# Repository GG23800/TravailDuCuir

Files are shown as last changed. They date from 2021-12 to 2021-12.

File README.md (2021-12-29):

# TravailDuCuir

Dans ce dossier presente certains projets de maroquinerie. On y trouvera les patrons utilisé quelques conseils éventuels pour la fabrication. Les patrons peuvent être utilisé pour des projets personnels mais pas pour faire des pièces qui seront vendues sans autorisation préalable de l'auteur.

## Pièce présentent dans ce dossier

### Sacoche de boules de pétanque



## Recettes

### Colle de farine

Pour coller le cuir j'utilise une simple colle de farine. Cette colle permet est colle "faible", elle permet de coller deux bouts de cuir entre eux mais la fixation n'est pas très solide. Elle est suffisante pour le maintient afin de coudre ensuite les pièces de cuir.

Pour la préparer :

- 2-3 cuillères à soupe de farine
- 1 cuillère à caffé de sucre en poudre (optionnel)
- un verre d'eau

Tout mélanger dans une casserole et faire chauffer. Quand la préparation commence à épaissir, rajouter de l'eau si nécessaire pour obtenir la consistance voulue. Elle doit être visqueuse mais pas trop pour pouvoir être étalée.

Conserver la colle au frigot, elle se garde quelques jours.

### Encaustique

L'encaustique est composé de :

- une part de cire d'abeille
- une part d'essence de térébentine

On peut également rajouter de l'huile de lin.

L'encaustique est déposé en finition, il nourrit le cuir et sert à imperméabiliser le cuir. Plus on en met plus l'imperméabilisaiton sera efficace. Par contre si on en met trop sur du cuir souple, il peut craqueler et faire apparaitre des tâche blanches. La première couche peut être mise avec une brosse à dent souple ainsi il peut se déposer dans le couture pour les protéger. Ensuite on le frotte avec un tissu doux non pelucheux.

## Freecad

Pour creer un pdf avec le patron à l'échelle 1, on utilise freecad (logiciel de CAO open source). On commence par créer une nouvelle pièce (module part design), on défini la géométrie avec le module sketch, on extrude (il est nécessaire de faire une pièce 3D pour exporter un dessin en coupe de la pièce). Une fois la pièce terminée, on ouvre le module drawing et le dessin s'intègrea avec la fonction insérer une projection orthogonale (on choisit la bonne vue pour l'affichage), on décoche la checkbox Echelle/position auto et on force l'échelle à 1. 
Sélectionner la page (du drawing) et appuyer sur la valeur de Editable texts, puis sur le bouton avec les trois petits points, on peut alors modifier les champs de la cartouche.
Finnalement on créé le fichier pdf via Fichier->Expoter au format pdf.

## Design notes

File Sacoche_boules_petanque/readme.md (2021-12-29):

# Sacoche de boules de pétanques

Ce dossier contient des patrons (fait à l'aide du logiciel freecad) pour découper les pièces permettant de monter une sacoche de boules de pétanques en cuir souple. Cette sacoche a été conçu pour des boules de 74 mm de diamètre.

## Matériel

- [Cuir de basane](https://www.decocuir.com/peau-cuir-basane-tannage-vegetal-france-065-c2x36476475)
- [Teinture acajou](https://www.decocuir.com/teinture-base-aqueuse-eco-flo-130ml-acajou-fonce-dark-mahogany-c2x35737638)
- [Fil de lin rouge](https://www.decocuir.com/fil-lin-cartonnette-15m-couture-mercerie-cuir-c2x36667080)
- [Fil de lin marron chocolat](https://www.decocuir.com/fil-lin-carde-cire-poisse-c2x36667077)
- [Boucle à rouleau](https://www.decocuir.com/boucle-a-rouleau-a-ardillon-laiton-vieilli-15-mm-c2x36300452) couleur laiton vieilli

## Pièces

Dans cette section on montre les patrons des différentes pièces composant la sacoche. Les fichiers des patrons peuvent être retrouvés dans le dossier [Patrons](./Patrons).

Attentions, les images insérées dans ce document ne sont pas à l'échelle, pour des patrons à l'échelle il faut utiliser les fichiers pdf du dossier Patrons.

Des lignes droites peuvent apparaître au milieu des patrons, ces lignes sont des lignes de symétrie qui reste affiché lors de la mise en plan.

### Anse



On a mis deux fichiers de patrons pour la anse car la dimension est supérieur à une feuille A4. Le fichier [Demi anse](./Patrons/Demi_anse.pdf) donne le patron de la moitié de la anse qui tient sur une page A4, il faudra l'imprimer deux fois et scotché bout à bout les deux parties. Sinon dans le fichier [Anse](./Patrons/Anse.pdf) on a mis la anse totale (elle dépasse légèrement du cadre) qu'il faudra imprimer sur une feuille A3.

La anse fait 400 mm de long pour 16 mm de large. Les pads sont des carrés de 30x30 mm.

### Support de boucle



Lien vers le [patron](./Patrons/Support_de_boucle.pdf) du support de boucle.

### Sangle



Lien vers le [patron](./Patrons/Sangle.pdf) de la sangle.

Pour plus de solidité (et avoir de la fleur de chaque côté de la anse) nous l'avons doublé. Dû à la souplesse du patron en papier et du cuir les deux pièces ne sont pas très bien superposées, il a donc fallu les égaliser après collage (avant couture).

### Côté

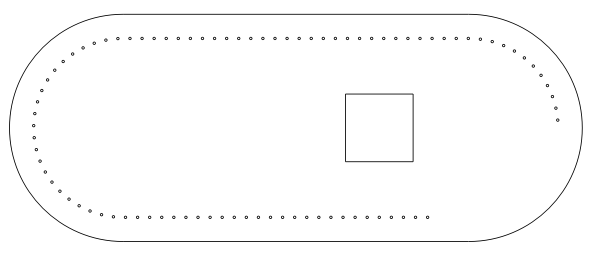
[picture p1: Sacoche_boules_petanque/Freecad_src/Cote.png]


Lien vers le [patron](./Patrons/Cote.pdf) du côté.

Attention pour les deux côtés de la sacoche sont simétriques, donc pour ce qui concerne la couture il faut utiliser le patron dans un sens pour le côté gauche et dans l'autre pour le côté droit.

On a mis une distance de 10 mm entre le bord de la pièce et la ligne de couture. Les points de couture sont espacés de 5 mm. Le carré représente le positionnement de la anse sur cette pièce, la dimension est légèrement inférieur (de 2 mm) au bout de la anse pour donner un indicateur de dépose de colle et ne pas avoir de marque qui peuvent dépasser de la anse une fois fixé. 

### Pourtour



Le pourtour est la plus grande pièce du projet. Elle fait environ 640 mm de long, soit deux longueurs de feuille A4 plus l'arrondi. Le patron est donc enregistré au [format A3](./Patrons/Pourtour_A3.pdf) en plusieurs parties. Il faudra les scotcher bout à bout. Le patron au [format 4A](./Patrons/Pourtour_A4.pdf) montre la pièce complète.

On a mis une distance de 10 mm entre le bord de la pièce et la ligne de couture. Les points de couture sont espacés de 5 mm.

## Montage

La anse étant faite dans le même cuir que tout le reste, on l'a doublé pour augmenter sa solidité. Il faut donc découper deux fois le patron de la anse, coller les deux parties ensemble puis les coudres avec un point sellier. Ne pas oublié le travail des tranches (abat carre, ponsage, gomme adragante).

Pour le support de boucle, il préférable de parer la partie à coller pour fixer la boucle. Une fois collée, on coud pour la solidité. Sur le patron, l'enchapure n'a pas les boûts arrondis, on peut le faire à l'emporte pièce. Il n'y a pas de patron à l'heure actuelle, mais il est également préférable de faire un passant. Ce passant doit être mis sur le patron avant la mise en place de la boucle.

Les côtés doivent être découpés en deux exemplaires. La anse est fixée sur chaque côté puis cousue. Une fois ceci effectué, on coud les côtés et le pourtour. Les côtés et le pourtoure doivent être cousu à l'envers (face teinte l'une contre l'autre), le perçage s'effectue avec une alène ronde. Le couture est doublée (type point sellier avec deux aiguilles). Cette couture a été faite avec le fil marron pour qu'elle soit discrète (toutes les autres coutures ont été faite au fil rouge).

Une fois la couture fini, on retourne la sacoche pour qu'elle soit à l'endroit.

Pour la permière sacoche, le support de boucle et la sangle ont été fixés et cousu après cette couture pour bien les positionner. Si les patrons était bien maitrisés on pourrai le faire avant.

### Remarques

Le pourtour est un peu grand et peut être réduit d'un ou deux centimètres.

La sangle est un peu grande et peut être réduit d'un centimètre.

Attention, le nombre de trou pour la couture des côté et du pourtour n'est pas maitrisé. Ces trous n'ont pas été marqués à l'alène sur la fleur mais au marqueur sur la croute. Les trous ont été percés au fur et à mesure puis quand la couture a été jugé suffisament haute (et pas trop) on s'est arrêté. Remonter un quart du demi-cercle supérieur des côtés est suffisant voir un peu trop.

## Photos 

Différentes photos du porjet sont enregistrées dans le dossier [Photos](./Photos).



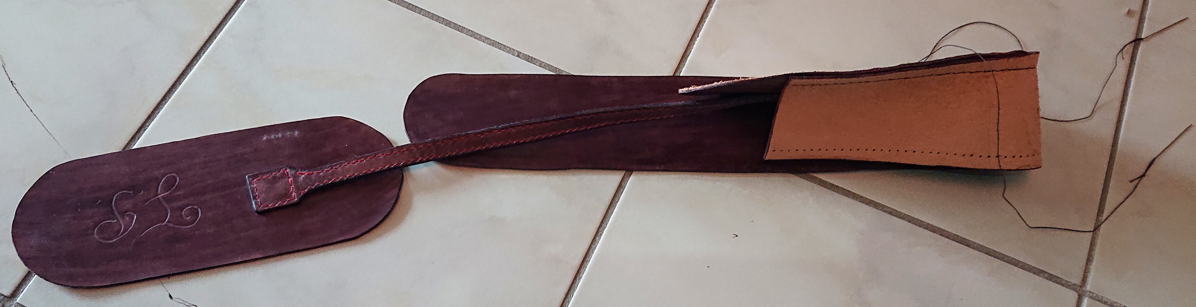
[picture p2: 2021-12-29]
Sacoche_boules_petanque/Photos/couture_pourtour.JPG

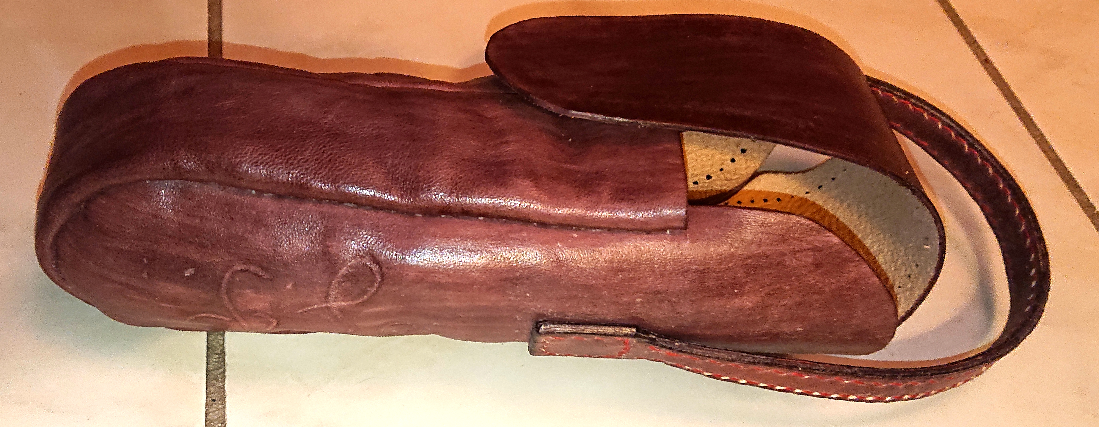
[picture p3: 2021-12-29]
Sacoche_boules_petanque/Photos/retourne.JPG

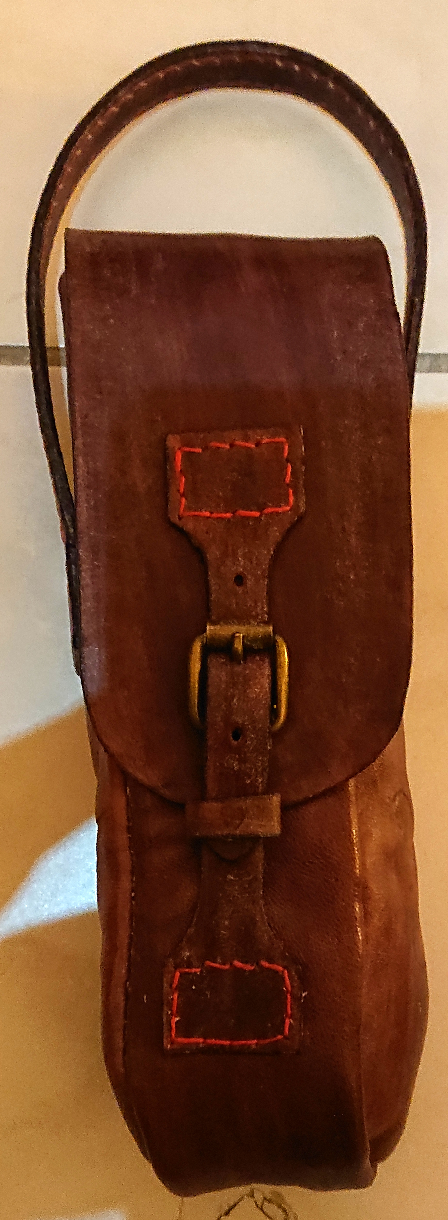
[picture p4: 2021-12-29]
Sacoche_boules_petanque/Photos/final2.JPG

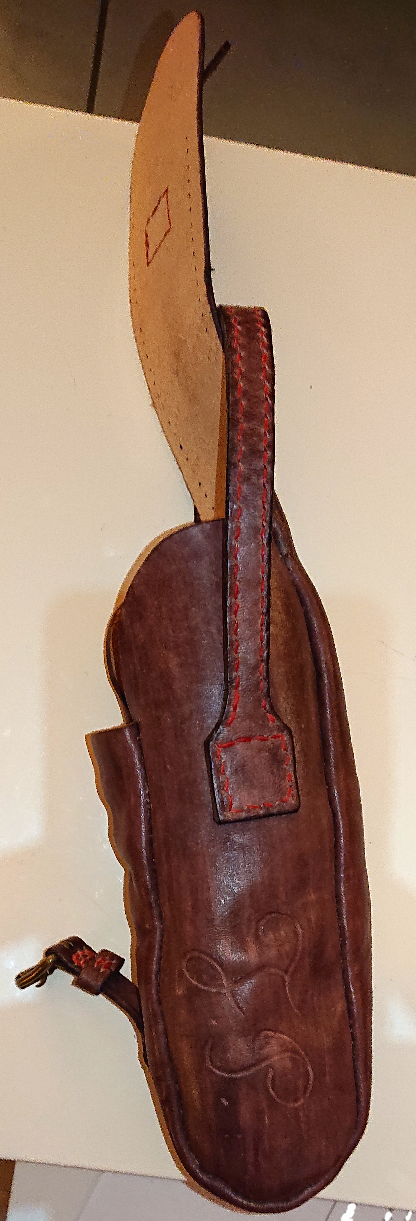
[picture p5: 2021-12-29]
Sacoche_boules_petanque/Photos/final1.JPG

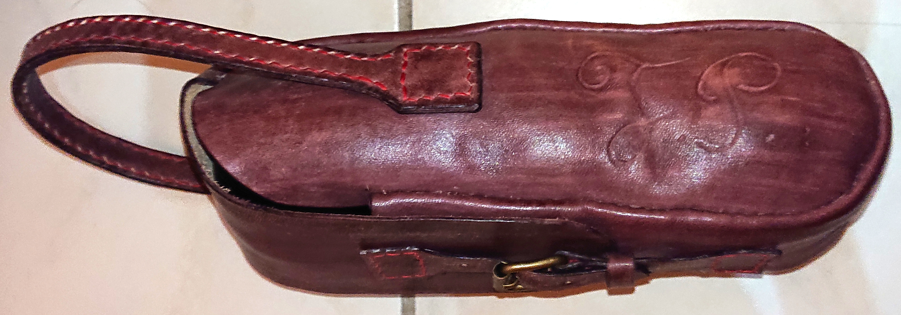
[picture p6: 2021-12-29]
Sacoche_boules_petanque/Photos/final3.JPG

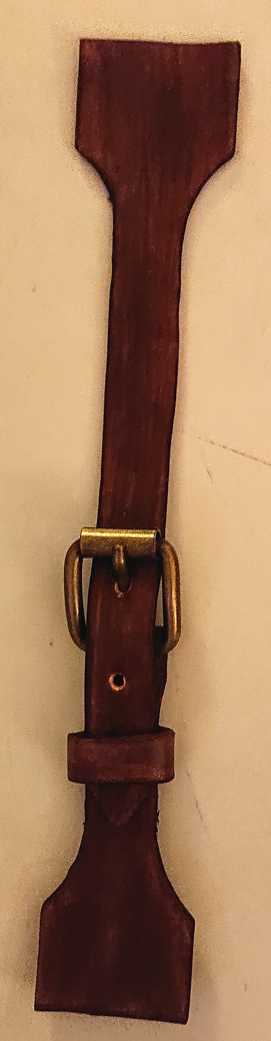
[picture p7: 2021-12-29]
Sacoche_boules_petanque/Photos/fermeture_face.JPG

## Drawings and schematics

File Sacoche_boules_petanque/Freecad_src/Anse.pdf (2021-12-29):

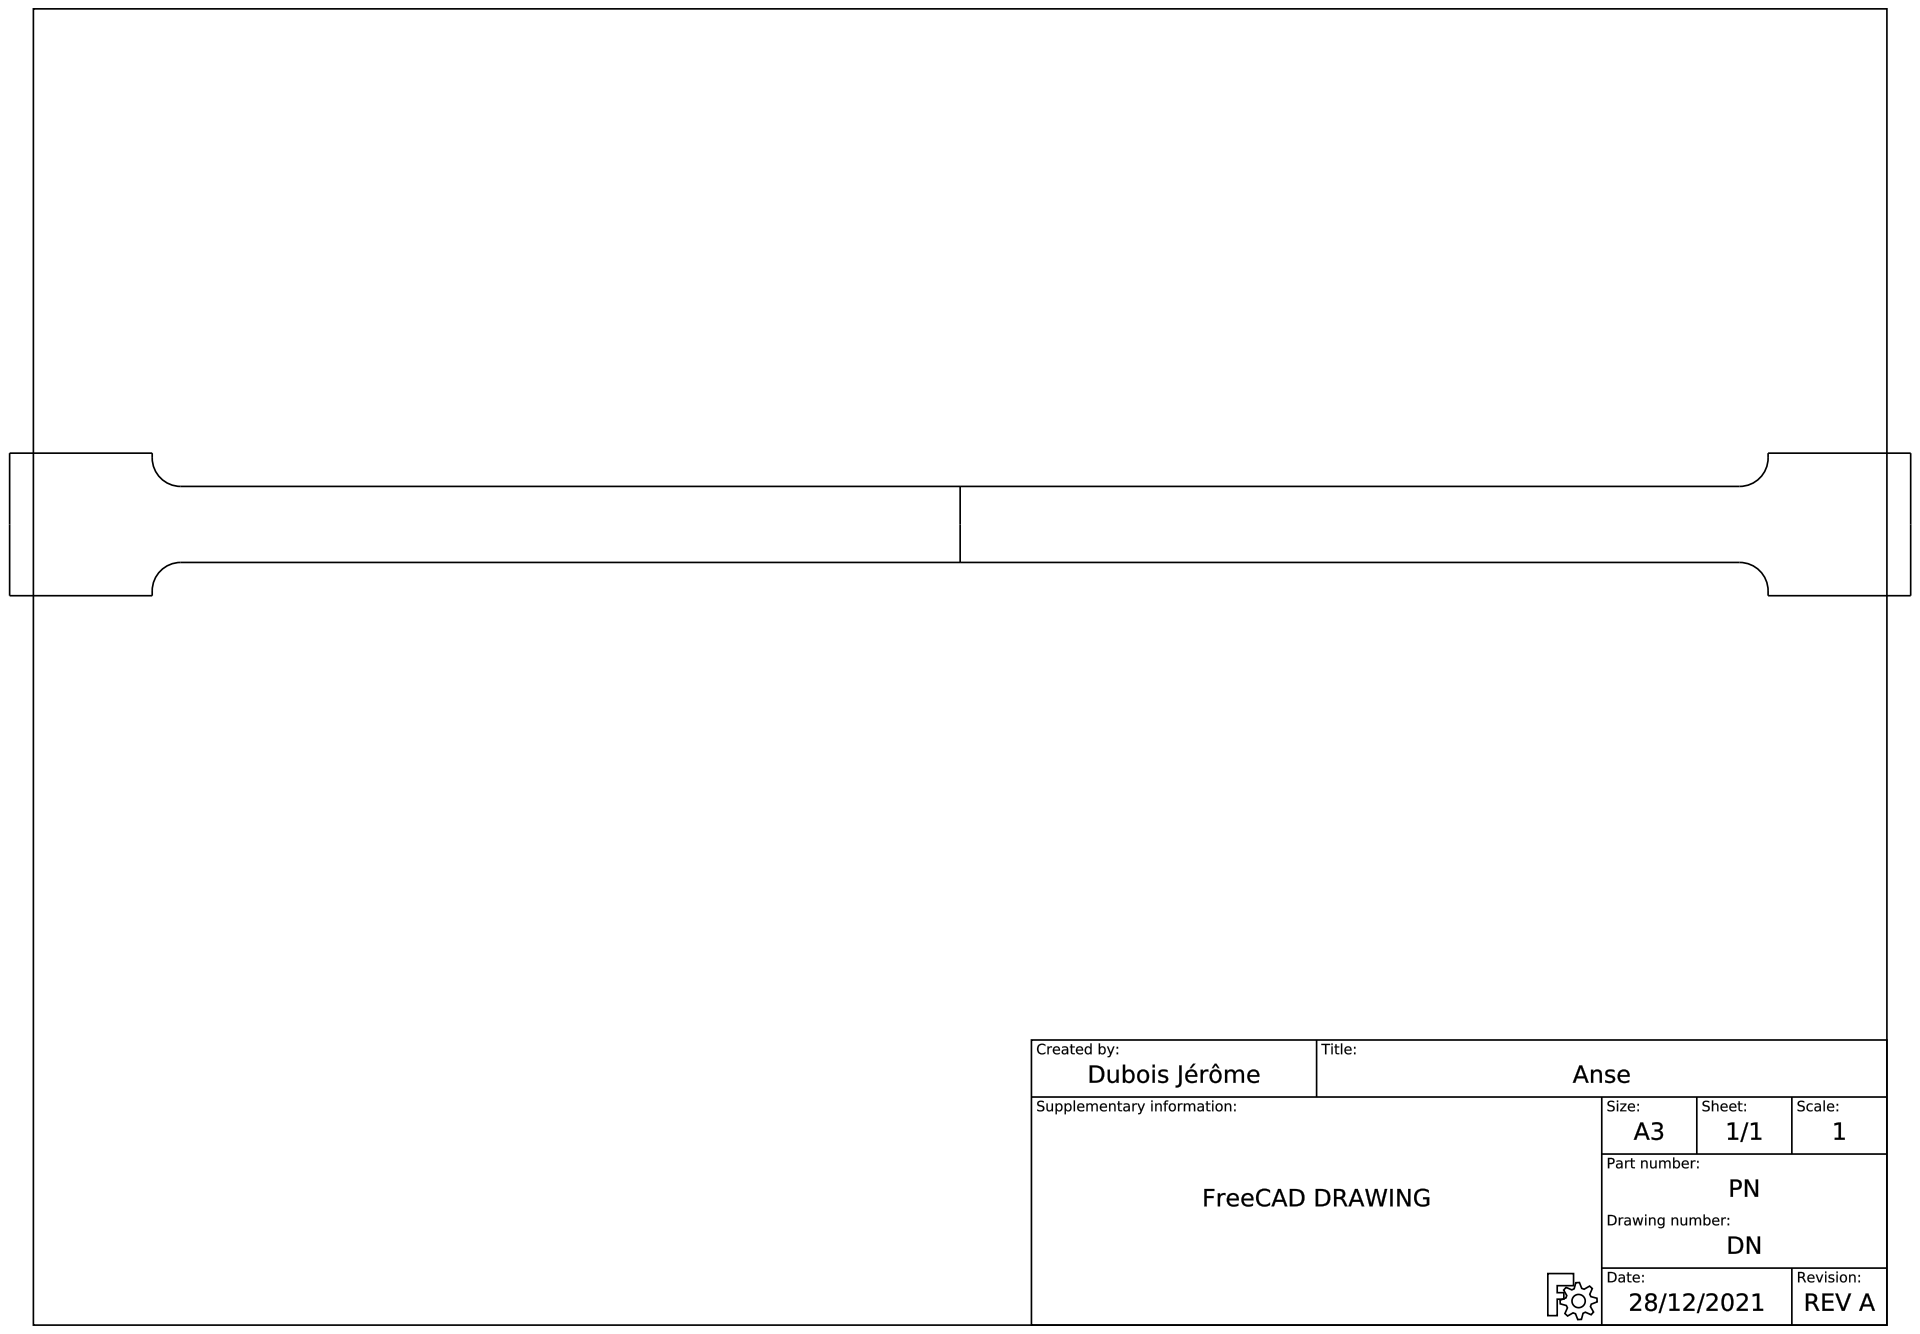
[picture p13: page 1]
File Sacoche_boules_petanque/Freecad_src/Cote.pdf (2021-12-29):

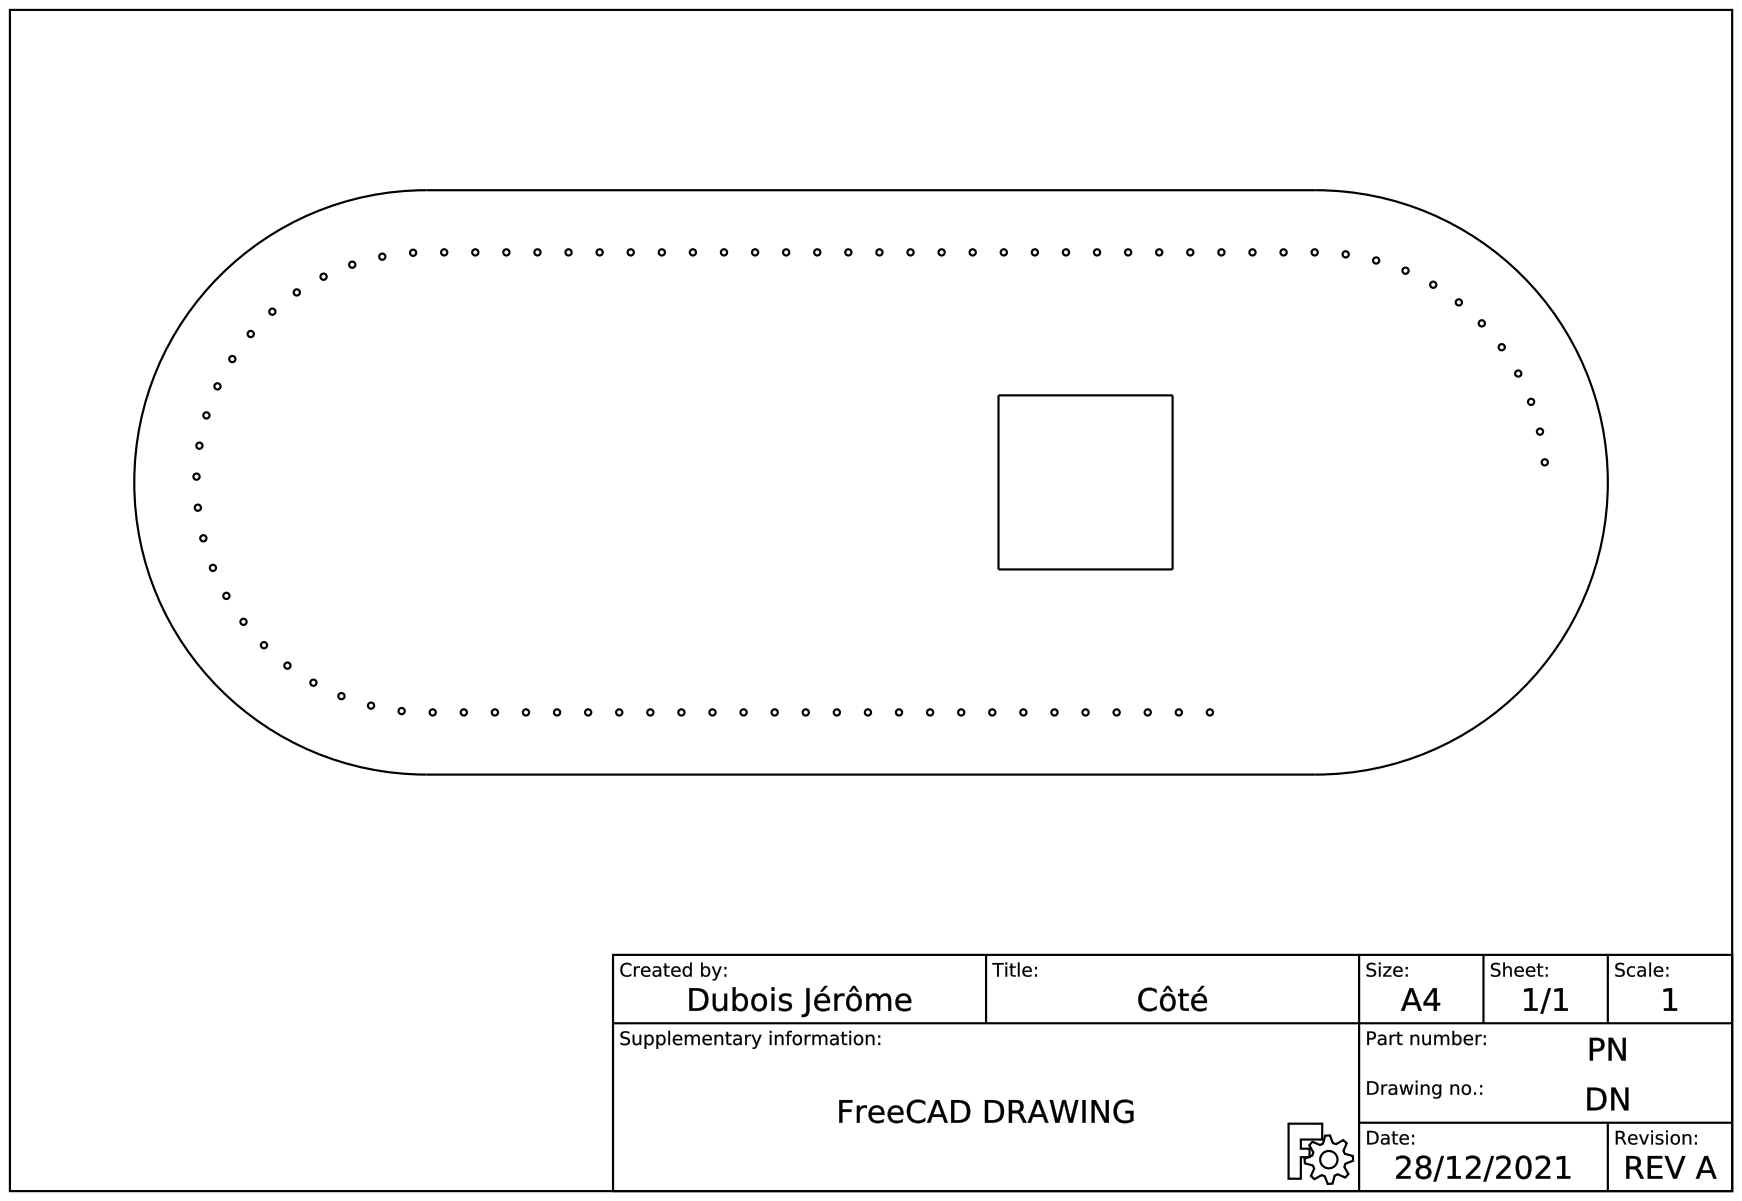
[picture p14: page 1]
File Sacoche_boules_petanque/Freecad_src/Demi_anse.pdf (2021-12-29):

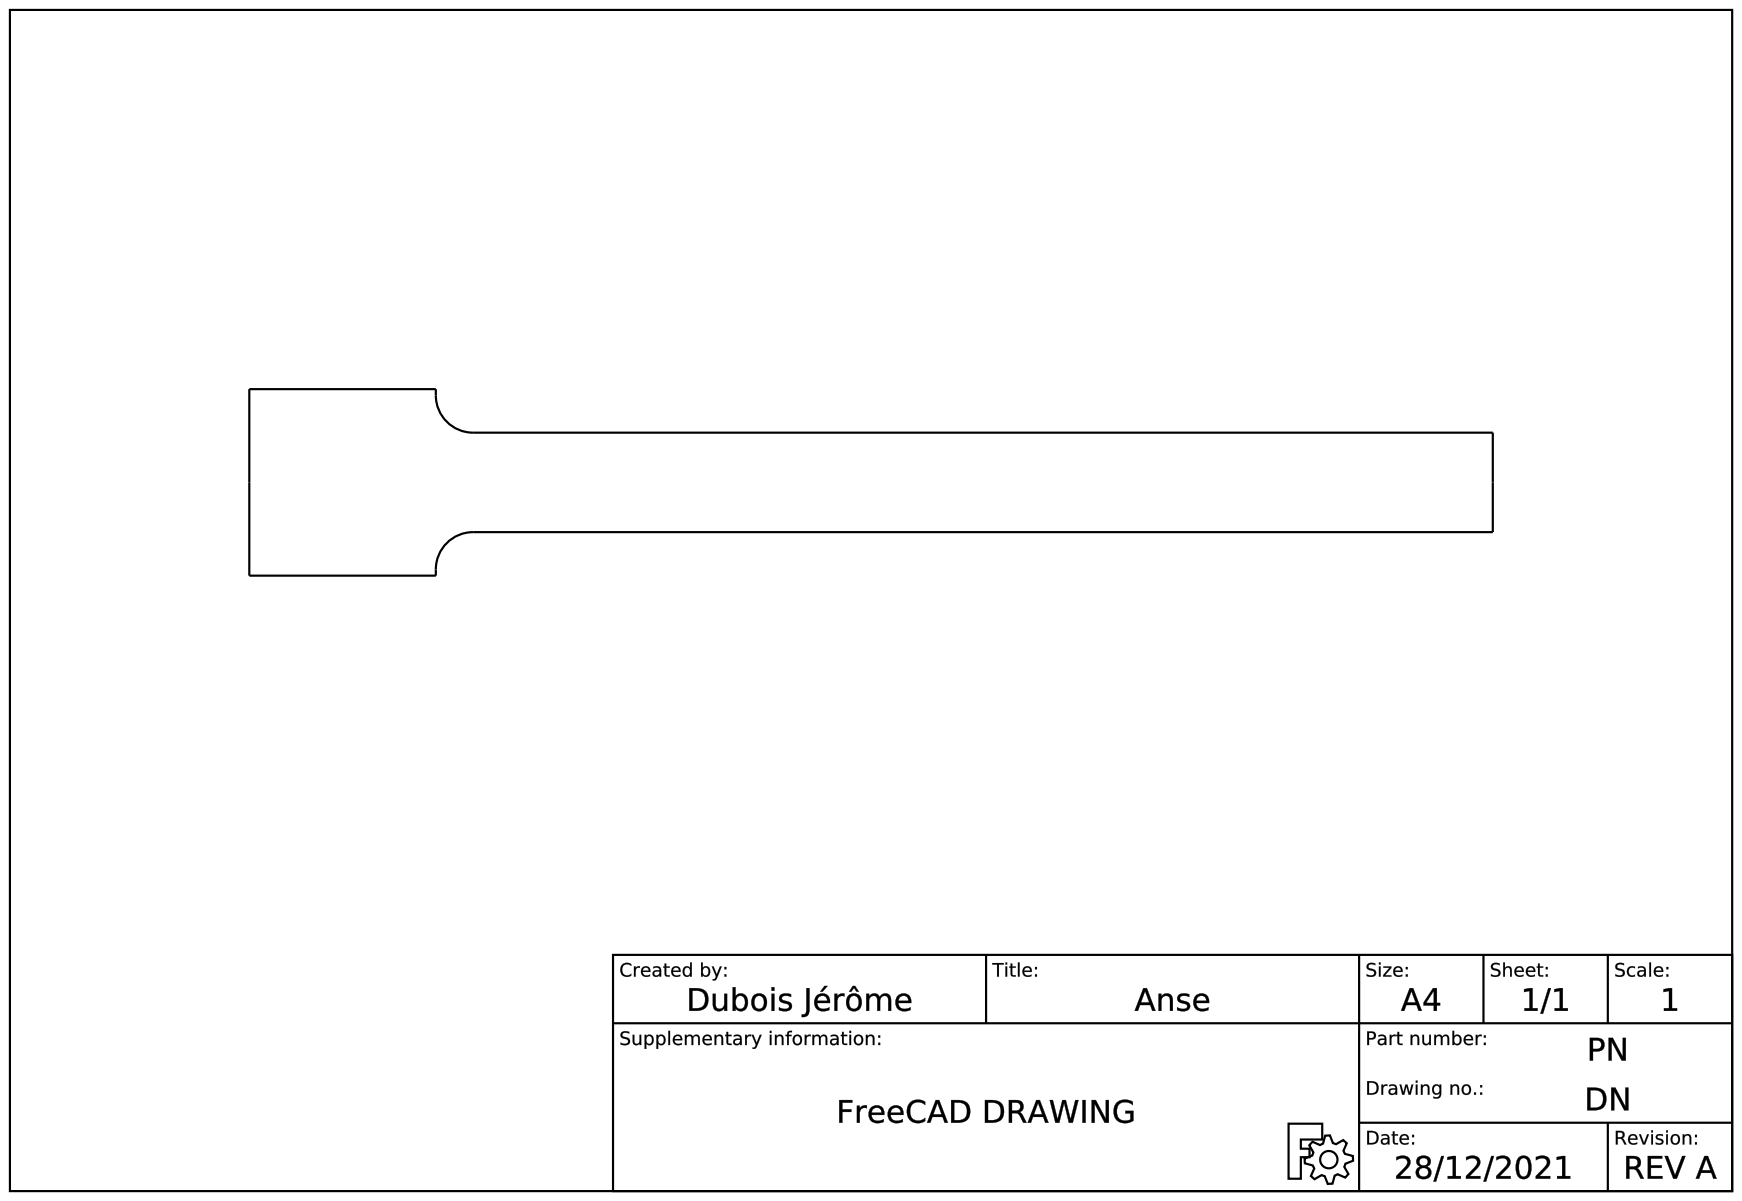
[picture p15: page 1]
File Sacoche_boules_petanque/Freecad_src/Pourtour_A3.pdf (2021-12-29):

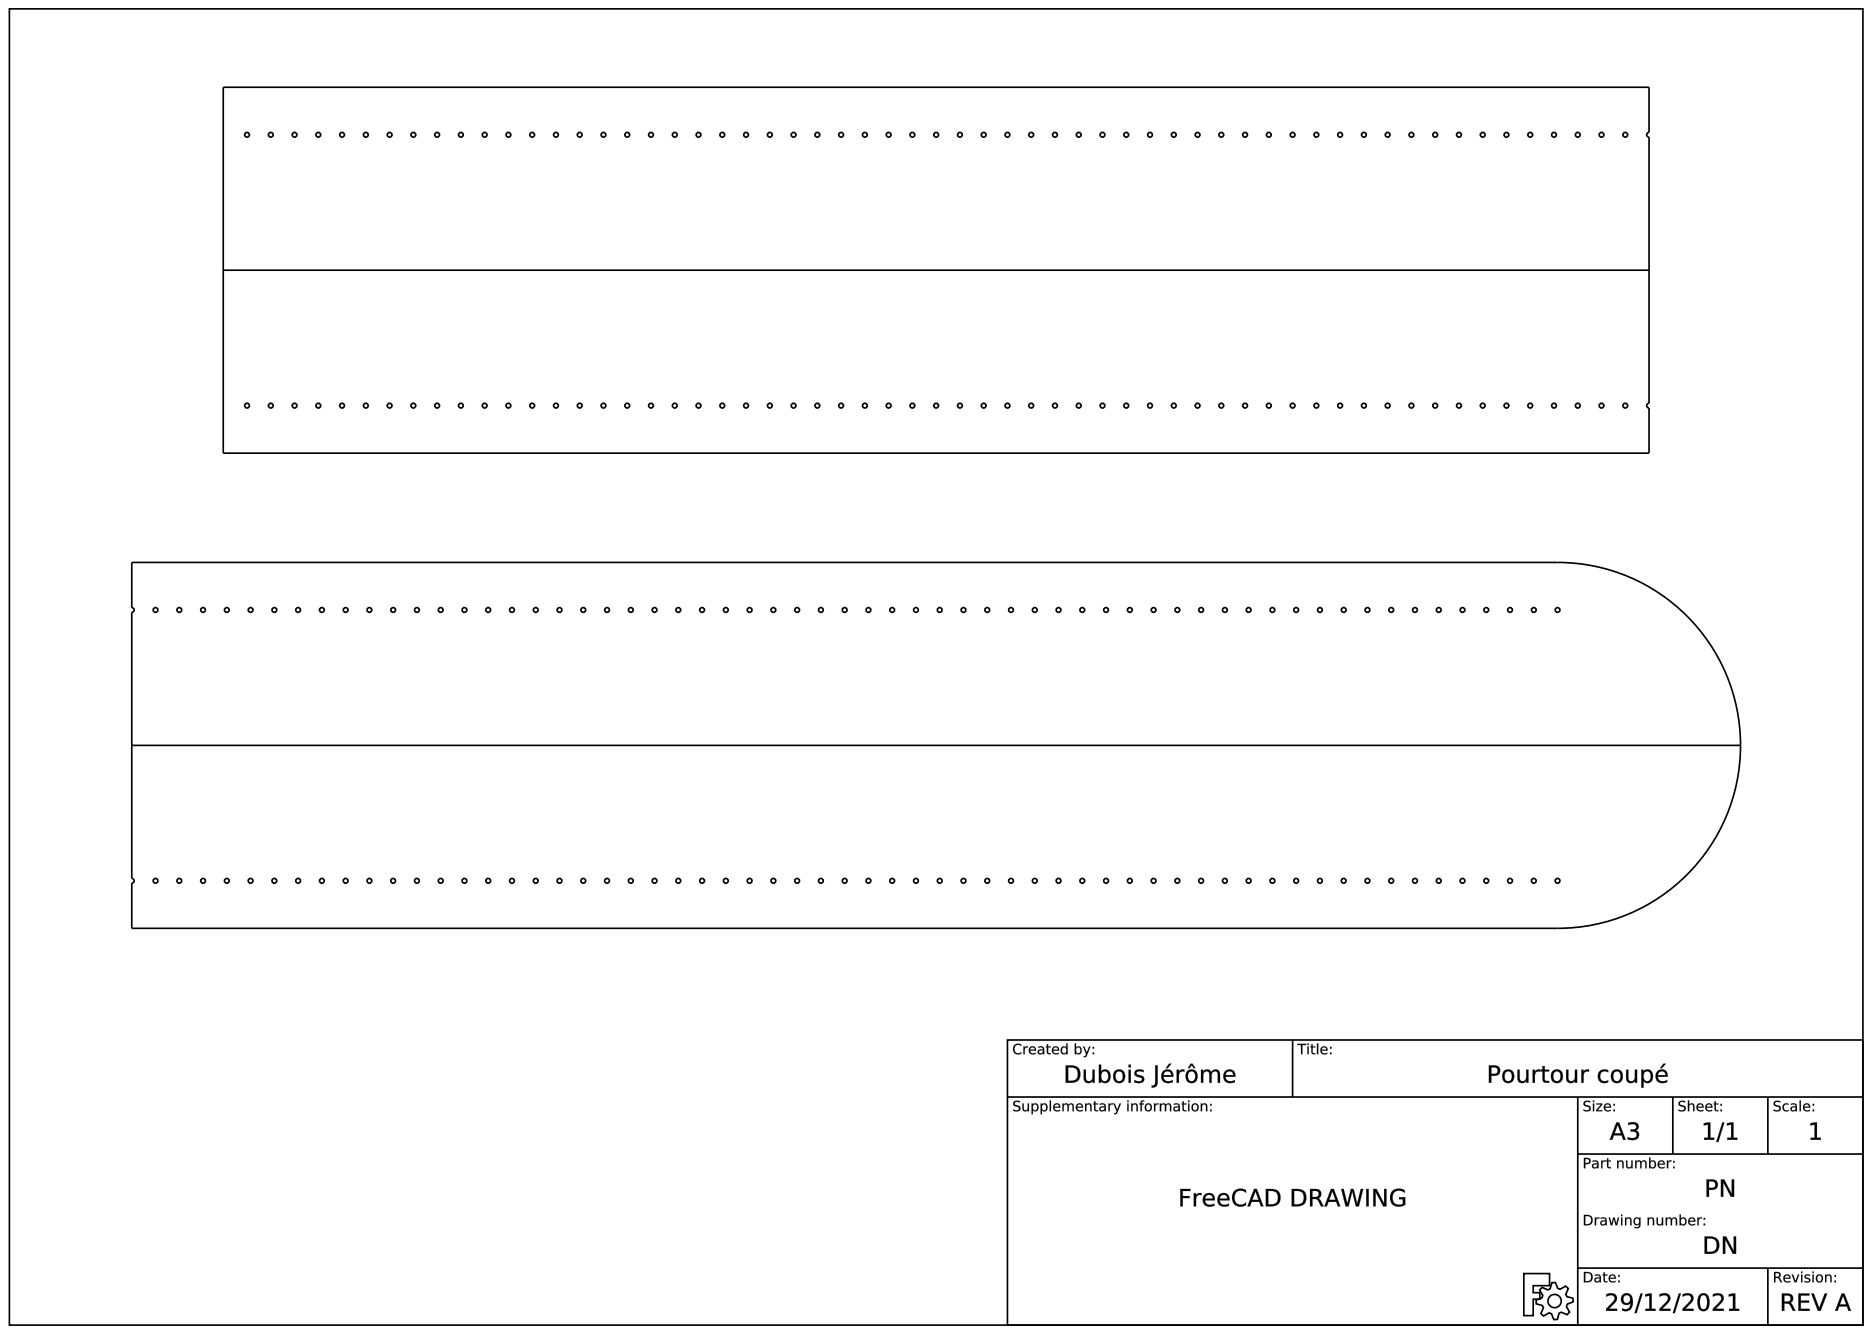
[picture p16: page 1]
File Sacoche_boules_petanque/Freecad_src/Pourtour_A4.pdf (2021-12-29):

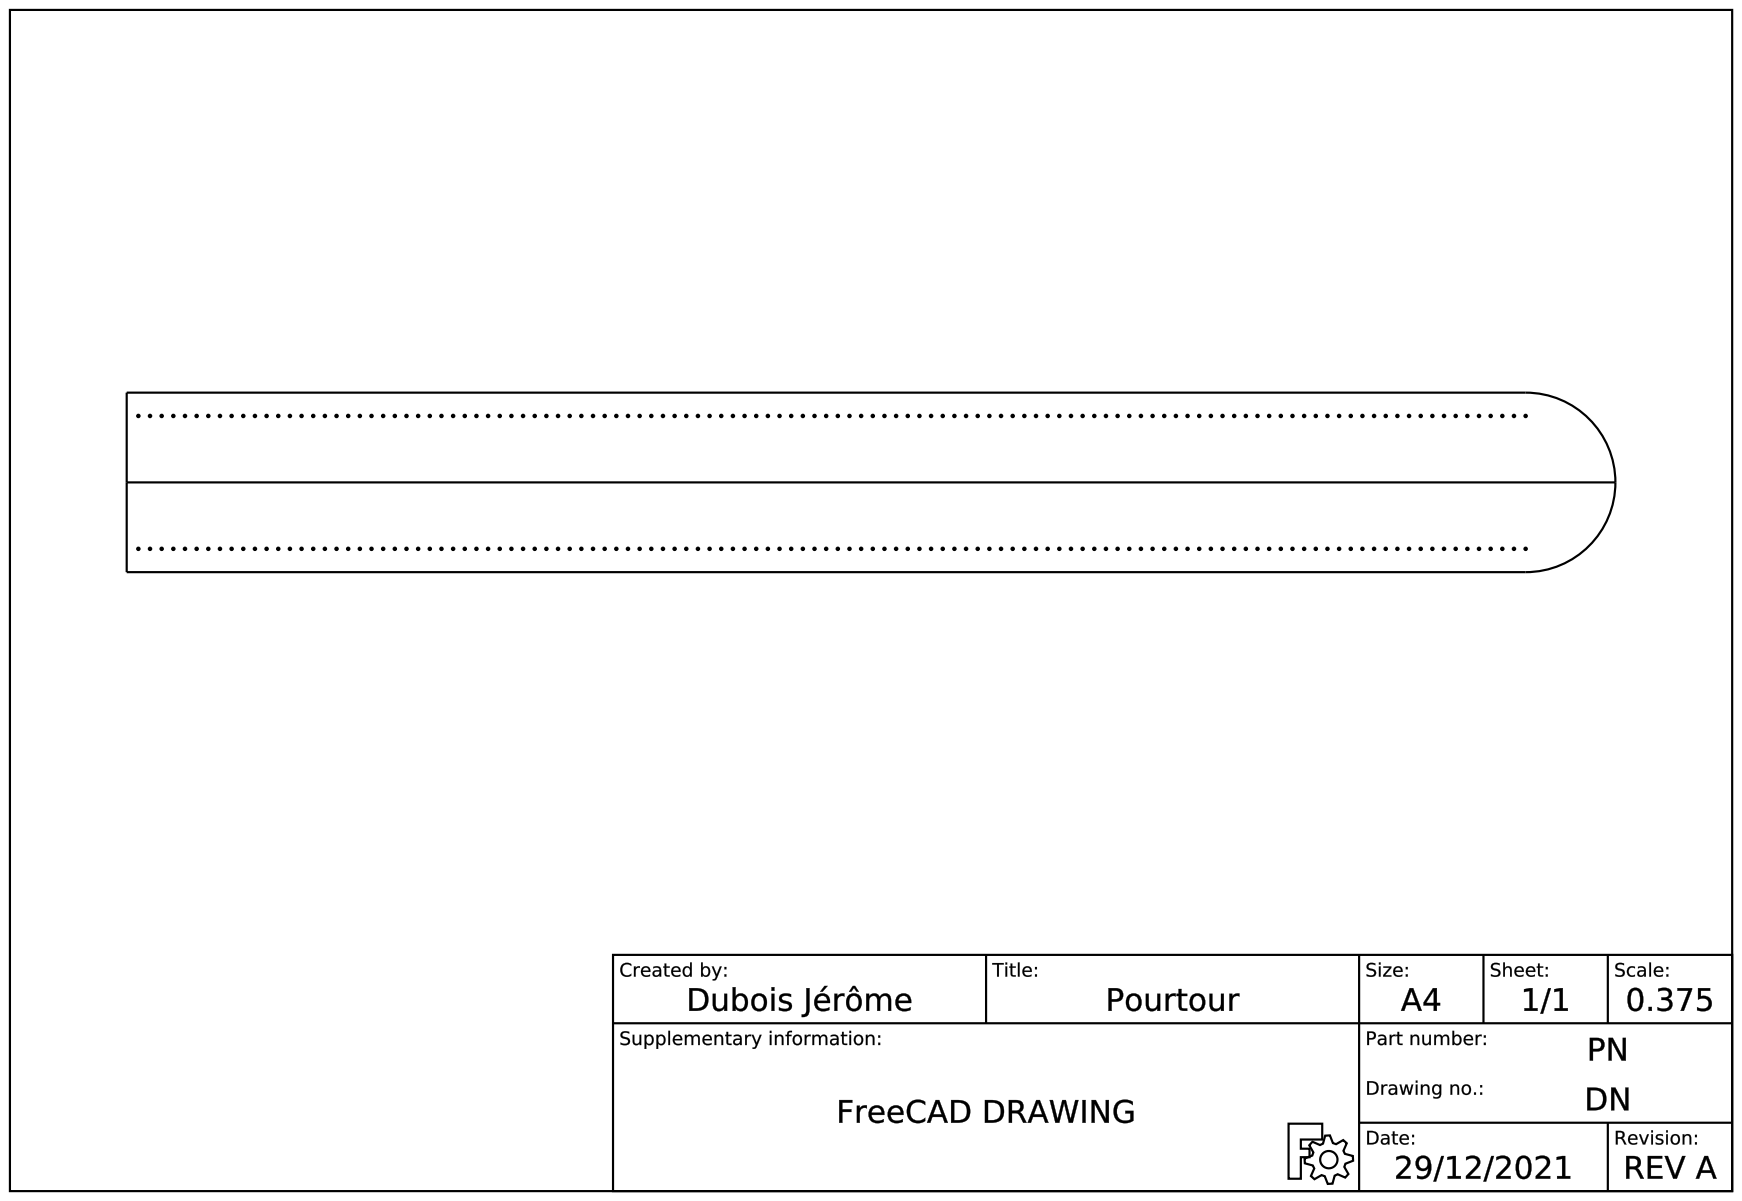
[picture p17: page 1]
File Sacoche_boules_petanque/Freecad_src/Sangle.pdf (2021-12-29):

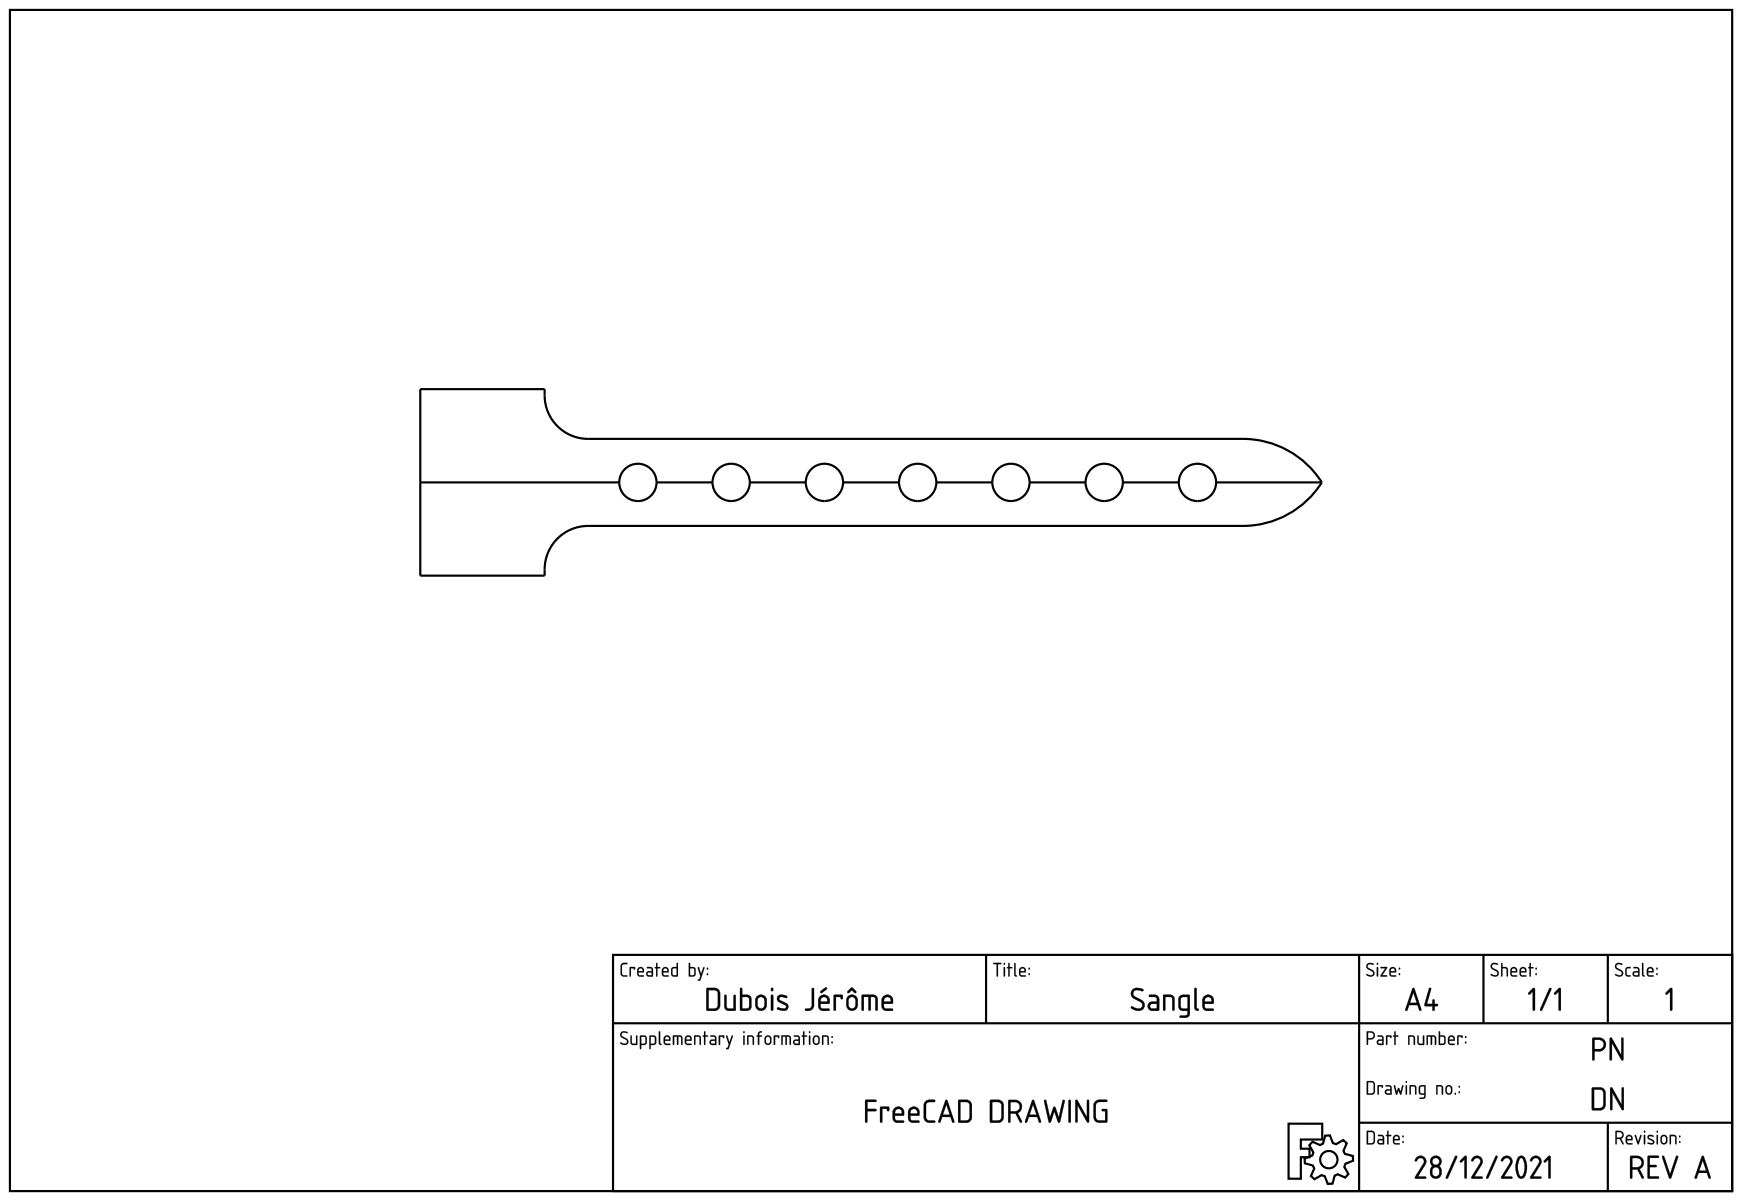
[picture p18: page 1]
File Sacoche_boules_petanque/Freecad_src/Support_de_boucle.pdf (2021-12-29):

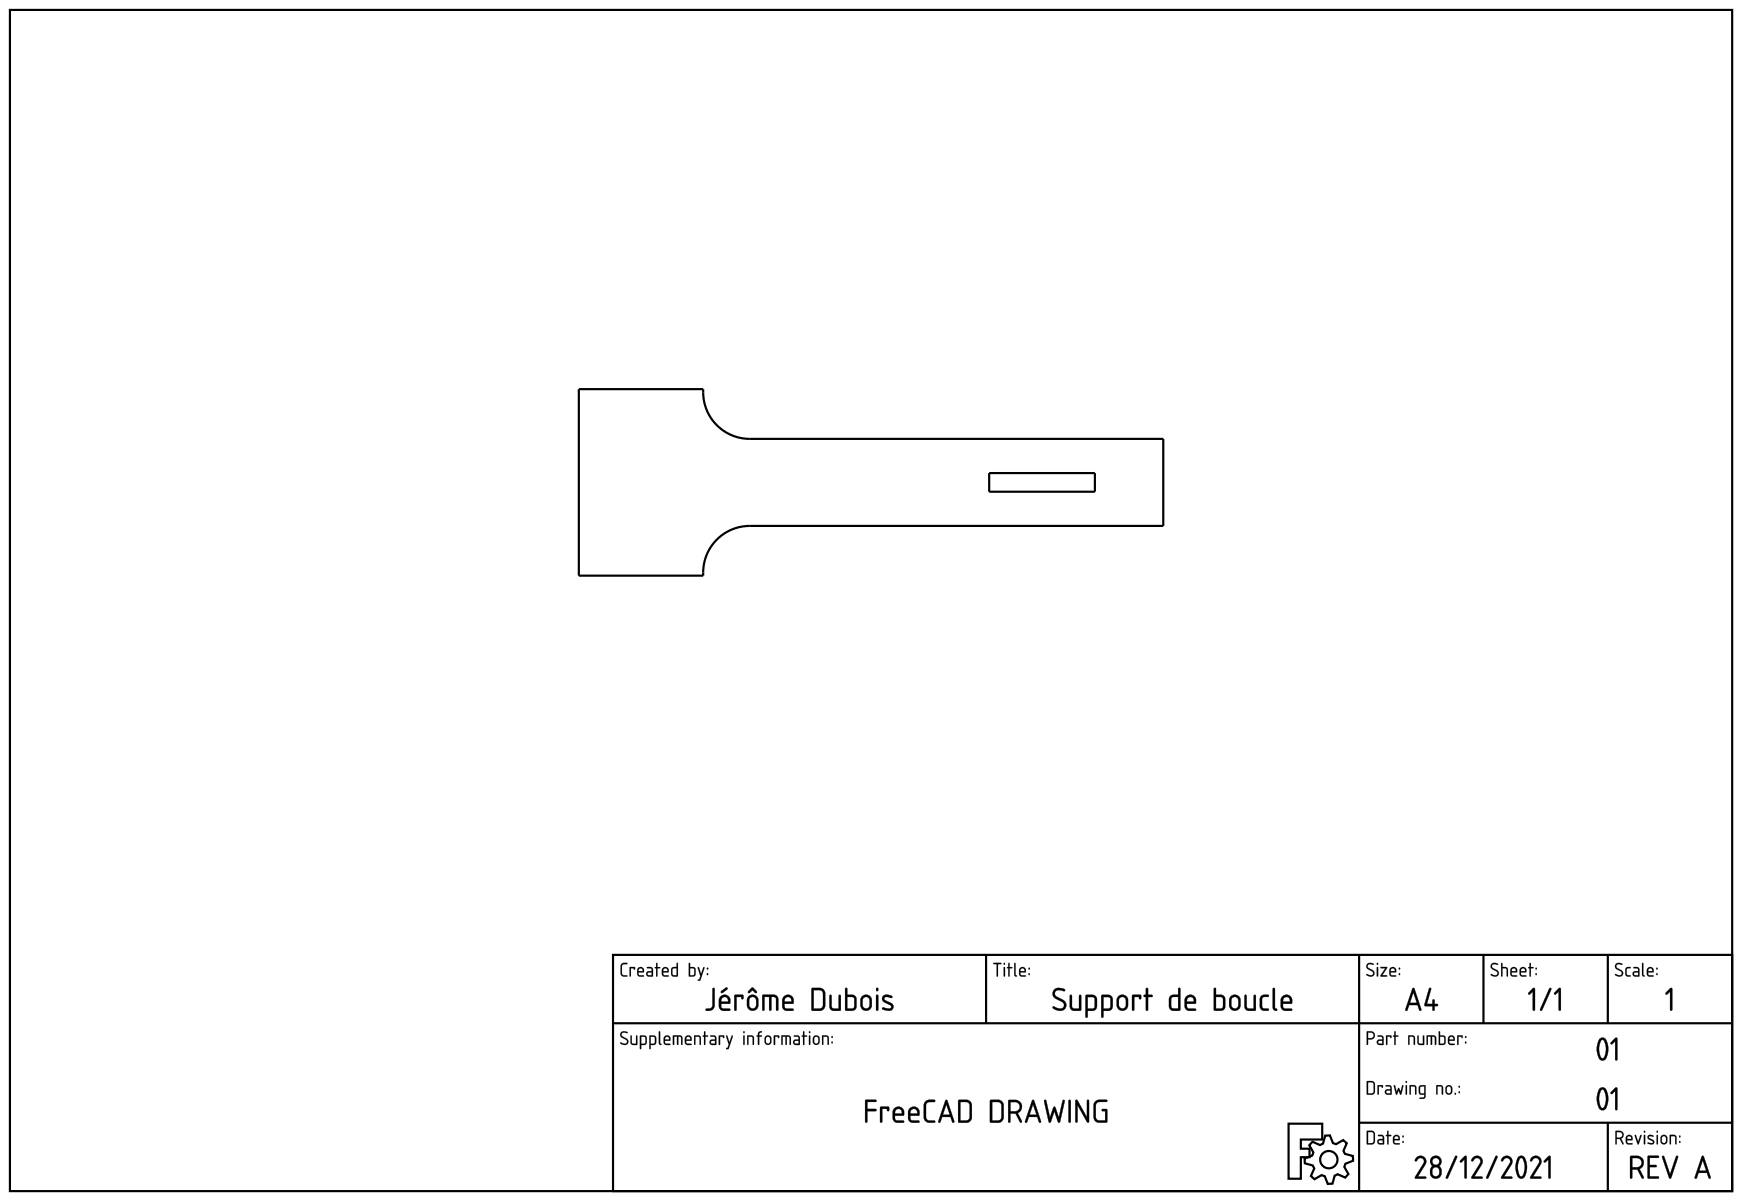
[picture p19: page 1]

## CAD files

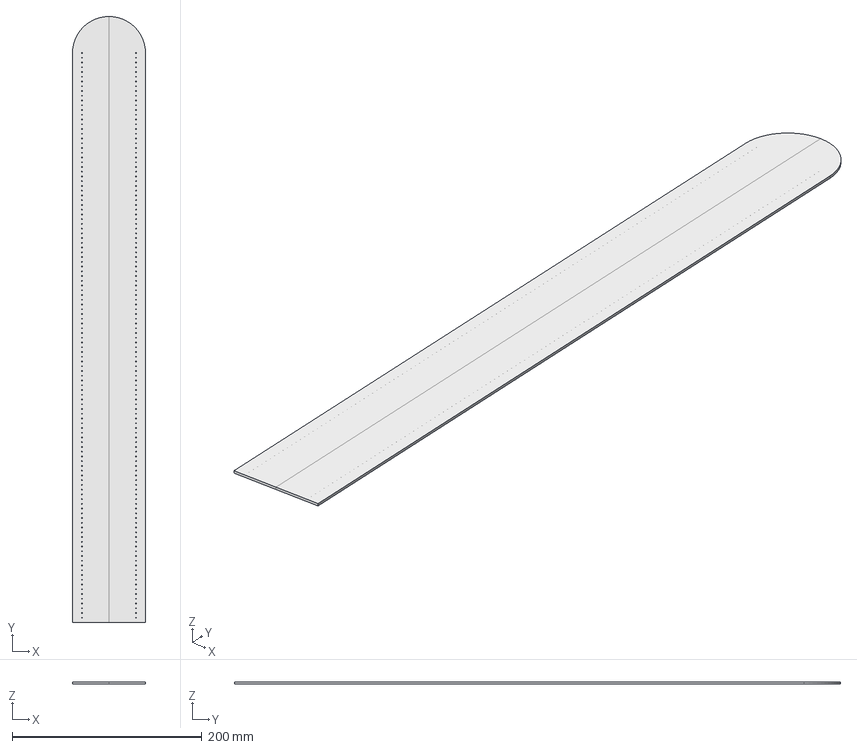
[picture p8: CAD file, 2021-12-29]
Sacoche_boules_petanque/Freecad_src/Pourtour.FCStd
77.0 x 638.5 x 2.00 mm

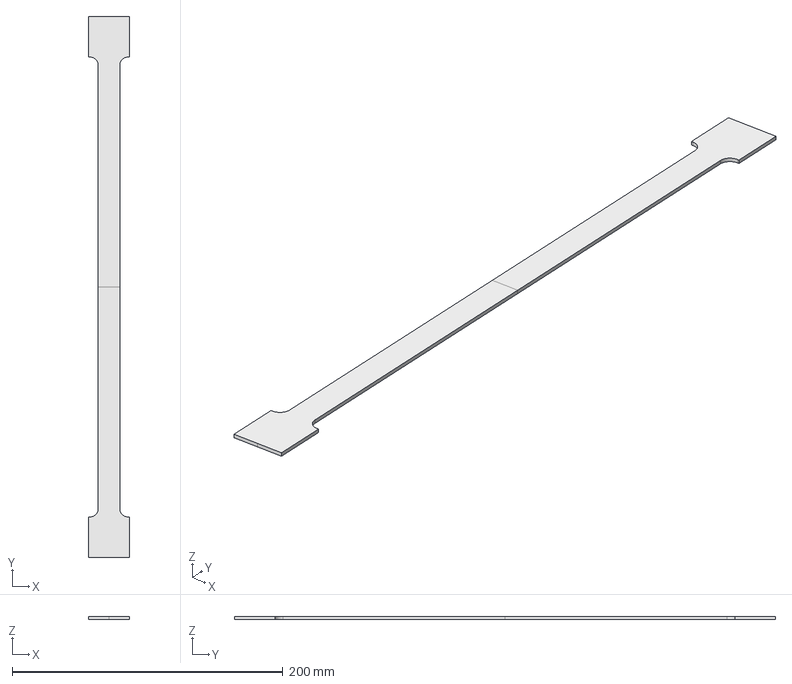
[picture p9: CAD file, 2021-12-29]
Sacoche_boules_petanque/Freecad_src/Anse.FCStd
30.0 x 400.0 x 2.00 mm

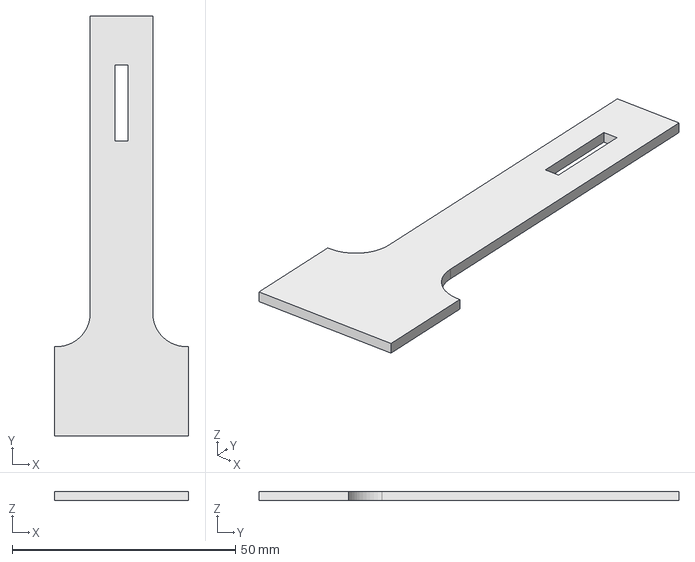
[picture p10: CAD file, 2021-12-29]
Sacoche_boules_petanque/Freecad_src/Support_boucle.FCStd
30.0 x 94.0 x 2.00 mm

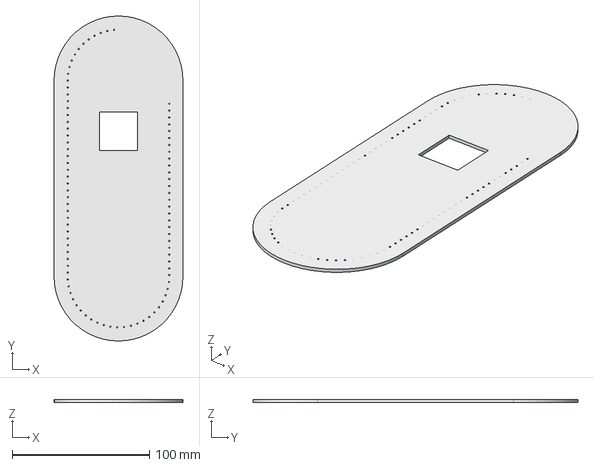
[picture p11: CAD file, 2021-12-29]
Sacoche_boules_petanque/Freecad_src/Cote.FCStd
94.0 x 237.0 x 2.00 mm

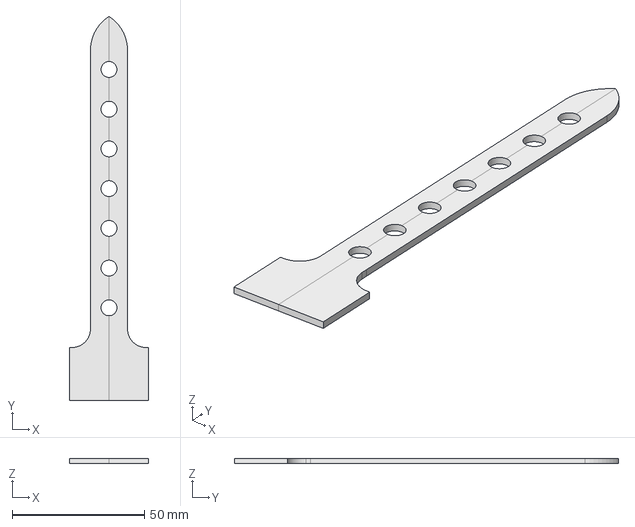
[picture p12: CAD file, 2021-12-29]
Sacoche_boules_petanque/Freecad_src/Sangle.FCStd
30.0 x 145.0 x 2.00 mm

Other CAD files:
Sacoche_boules_petanque/Freecad_src/Pourtour_coupe.FCStd
Sacoche_boules_petanque/Freecad_src/anse.FCStd
